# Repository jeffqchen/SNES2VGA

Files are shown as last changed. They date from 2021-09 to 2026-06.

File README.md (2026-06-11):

# SNES2VGA

SNES2VGA Dongle for Nintendo Consoles

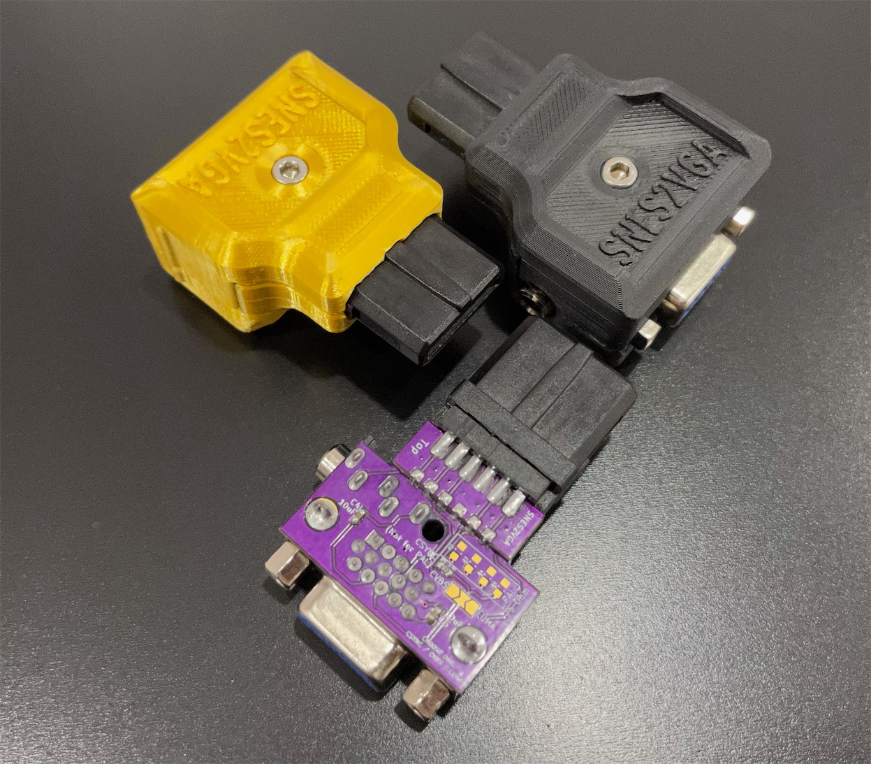
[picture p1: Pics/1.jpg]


## Introduction

This dongle takes the AV Multi output used on various Nintendo consoles and adapts them into HD15 (VGA), so you can use the commonly available VGA cable for transmitting RGBs video and stereo audio.

Note that consoles usually require RGB mods in order to output RGBs signal.

### Console Compatibility

#### Nintendo Entertainment System / Nintendo Famicom

The NES/Famicom do not generate or output RGB signals natively. They generate composite video and output it as-is or encode it to RF.

For them to output RGB, modding it with an [NESRGB](https://etim.net.au/nesrgb/) and the [Nintendo AV Multi style port](https://www.laserbear.net/products/nes-front-loader-snap-fit-multiout) is required.

*(If you installed an 8 or 9-pin MiniDin port, please check my [8DIN2VGA](https://github.com/jeffqchen/8DIN2VGA) and [9DIN2VGA](https://github.com/jeffqchen/9DIN2VGA) projects instead.)*

---------

#### Super NES / Super Famicom (Jr.)

- NTSC consoles not output RGB signals natively, and need to be modded to restore RGB output with [SNES RGB Bypass](https://github.com/borti4938/SNES_RGB_Bypass).
- PAL consoles output an RGB signal, but outputs 12V on the same pin where CSync is output on a NTSC console. Care must be taken when assembling the dongle.

---------

#### Nintendo 64

No native RGB output. Different models require different levels of modding to restore RGB output ([Simple RGB Bypass](https://voultar.com/index.php?route=product/product&product_id=50), [N64RGB](https://etim.net.au/n64rgb/), etc)

---------

#### GameCube

- NTSC consoles don't output RGB signals. RGB modding, such as [GCVideo](https://github.com/ikorb/gcvideo), is required.
- PAL consoles support RGB output natively, however the same `12V on CSync ordeal` is still present.

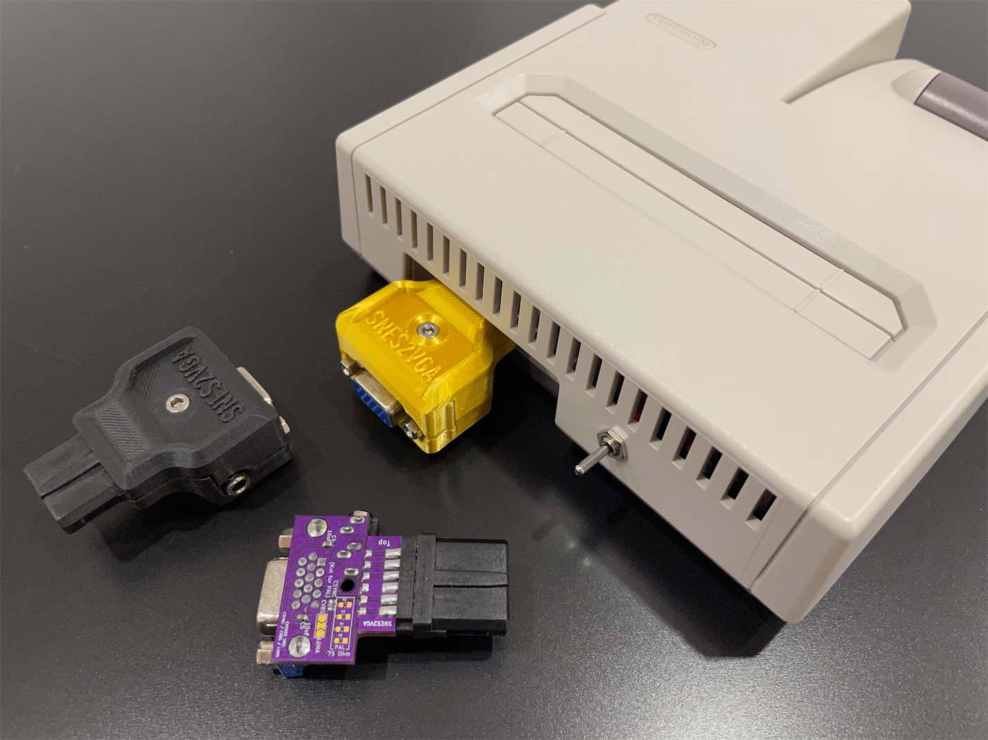
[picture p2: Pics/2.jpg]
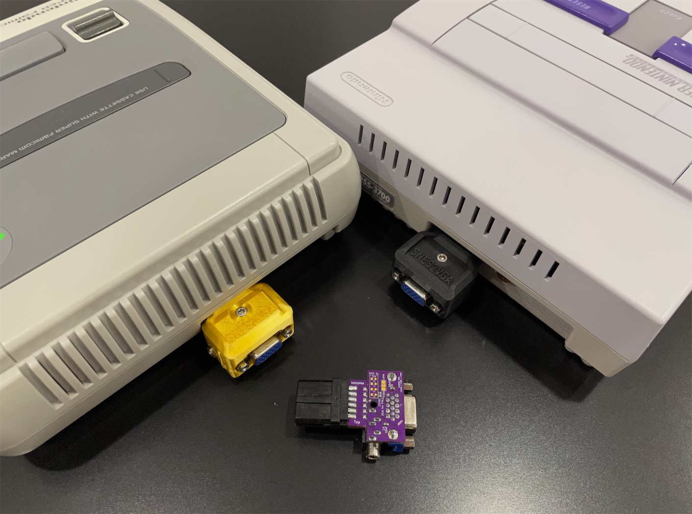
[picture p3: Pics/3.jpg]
 

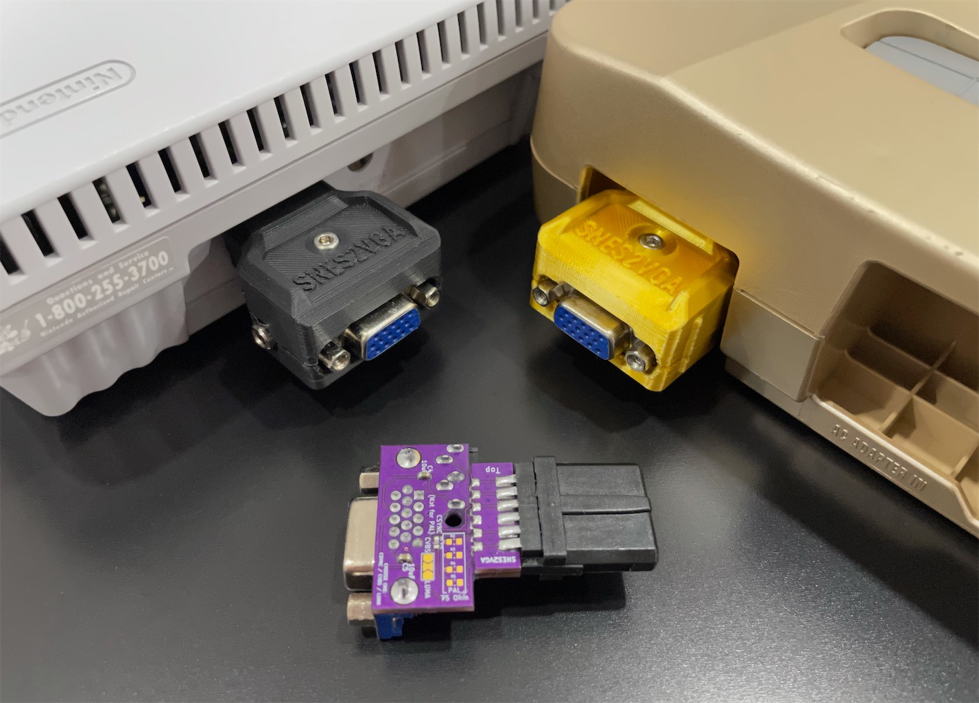
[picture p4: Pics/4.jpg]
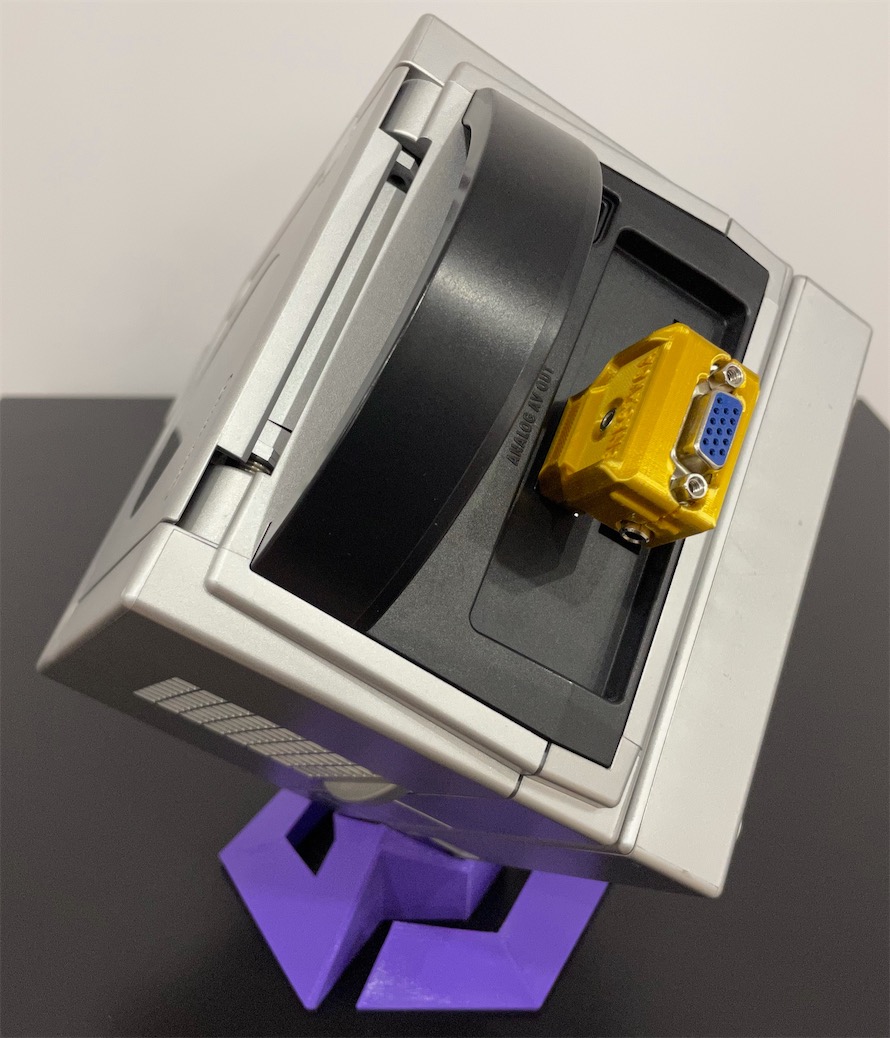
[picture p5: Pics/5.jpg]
 

## Sync

You can choose among CSync, Luma and composite video as your sync signal with the jumper on the PCB.

**WARNING**: PAL consoles output 12V on the CSync pin. CSync related components should NOT be populated if you are building this dongle for a PAL console.

## Audio

Audio can be sent within the VGA cable, or broken out from the 3.5mm jack on the dongle. Buzzing may be noticeable when audio is transmitted through the VGA cable in certain scenes in certain games. This is due to insufficient shielding in most VGA cables. If you find the buzzing to be annoying, please use the 3.5mm jack on the dongle for audio outputting. This will ensure the cleanest audio output.

------

## Variation - [N64D2VGA](./N64D2VGA)

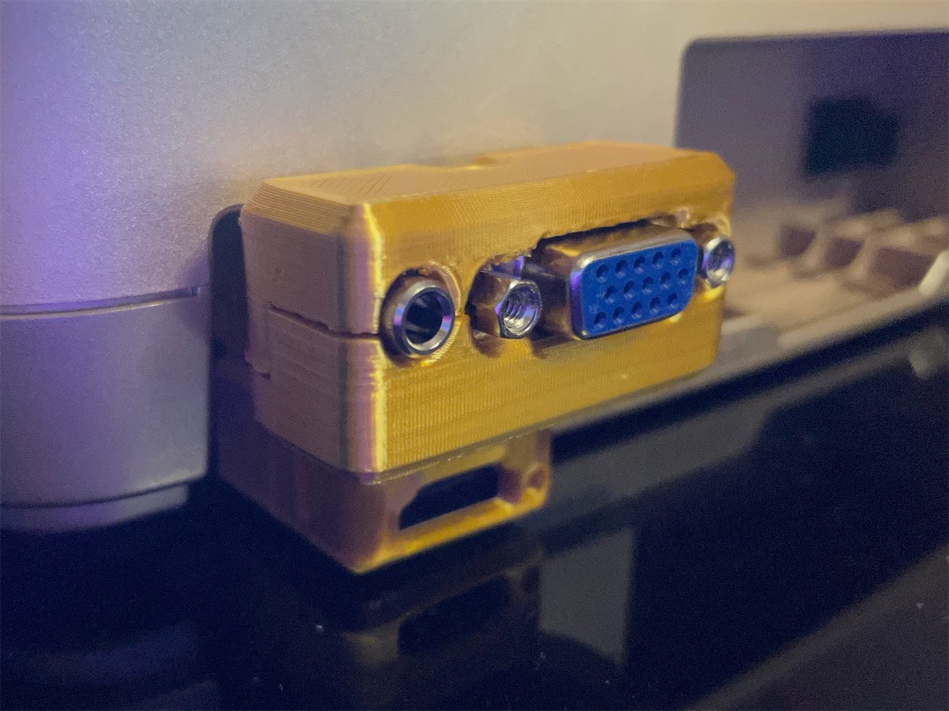
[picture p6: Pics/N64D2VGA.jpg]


This one works with my [N64Digital mini HDMI to Full HDMI Dongle](../../../N64Digital-Mini-To-Full-HDMI-Adapter) so you could achieve analogue RGBS & digital dual output with full sized plugs without interference.

-----

## Parts

### Common Parts

- PCB
  - [Main](https://oshpark.com/projects/JstxPxyZ)
  - [Sub](https://oshpark.com/shared_projects/RpSdS3qo)

- Nintendo AV Plug - [Link](https://github.com/jeffqchen/JeffParts/blob/main/Connectors/Nintendo%20AV%20Plug/info.md)

- VGA Port Slim, Female - [Link](https://github.com/jeffqchen/JeffParts/blob/main/Connectors/HD15/Slim/Female%20PCB/info.md)

- Vertical 3.5mm Headphone Jack - [Link](https://github.com/jeffqchen/JeffParts/blob/main/Connectors/3.5mm%20Audio%20Jack/Vertical%205-Pin%20PCB/info.md)

- [1x] M3x20mm screw and nut - [Link](https://github.com/jeffqchen/JeffParts/blob/main/Parts/M2%20M3%20Hex%20Screw%20%26%20Nut/info.md)

- [2x] Imperials 0603 SMD Capacitor 6.3V 10uF - C4, C5

- 3D Printed Shell
  - [Top](https://github.com/jeffqchen/SNES2VGA/blob/main/3D%20Print/SNES2VGA/Top.stl)
  - [Bottom](https://github.com/jeffqchen/SNES2VGA/blob/main/3D%20Print/SNES2VGA/Bottom.stl)

---

### NTSC Configuration

- C1, C2, C3: [3x] 220uF / 6.3V / Imperial 1206 Size - [Link](https://github.com/jeffqchen/JeffParts/blob/main/Components/220uF%20SMD%20Cap/info.md)
- [1x] Imperial SMD 0603 Resistor 470 Ohm - R1, **ONLY** if you choose CSync

---

### PAL Configuration

- C6: [1x] 220uF / 6.3V / Imperial 1206 Size - [Link](https://github.com/jeffqchen/JeffParts/blob/main/Components/220uF%20SMD%20Cap/info.md)
- [4x] Imperial SMD 0603 Resistor 75 Ohm - R2, R3, R4, R5

---

## Printing the Shell

Print the files with the split face facing downwards.

Print with support.

For a better mating surface finishing, use raft for bed adhesion.

---

## PCB Assembly

### Solder sub PCB to the main

First, align the sub PCB on top of the main PCB, align with the helper line and make sure the correct sides are facing the outside. Solder the two outside-most castellated pins and pads one by one, making sure the outside of the two boards are flush, so the plug can be soldered properly. Then proceed to solder the rest of the castellated pins to the pads.

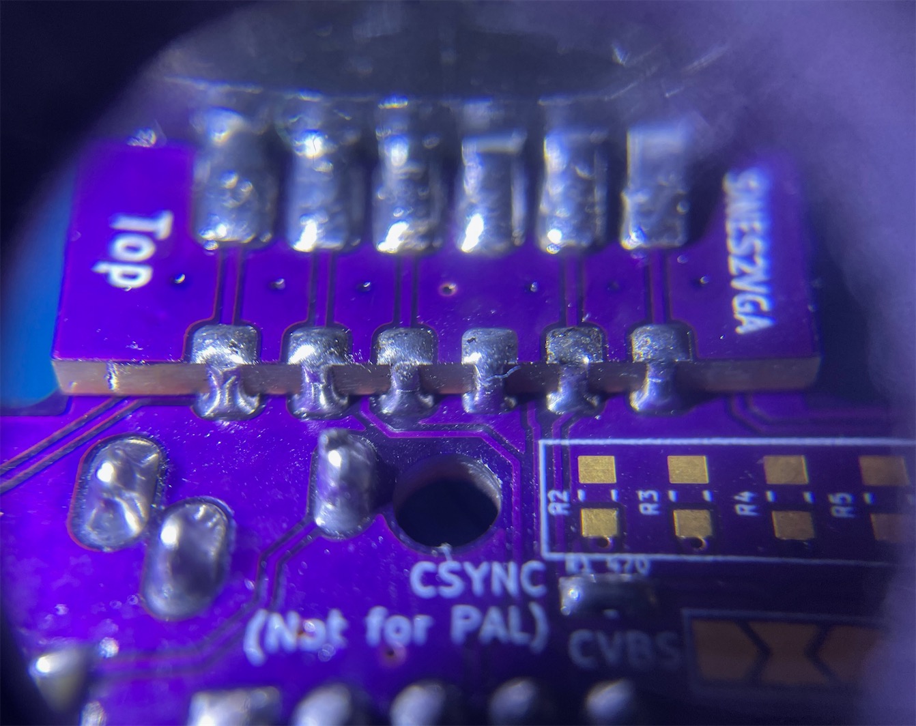
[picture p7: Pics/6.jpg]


### Solder on the video plug

Next, take a Nintendo video plug. Note the pins on the soldering side are sticking out straight. Now **bend** both rows of the pins inwards, with the help of the edge of a table. This way, the pins will actually be able to touch the pads on the PCB compound.

Tuck the plug onto the compound PCB. Make sure the plug is pointing the correct way up - the notched side of the plug is up, and the side with the smaller sub PCB is up. Align the pins to the pads as good as possible. Make sure there is no gap between the plug and the PCB on the mating edge. Then, solder one pin on each side with a generous amount of solder. Remelt and adjust the position if needed. Then proceed and solder the rest of the pins to the PCB with generous amount of solder.

### SMD Components

Solder on the SMD components. Note for NTSC and PAL consoles, the component configurations are **quite different**. Please follow the instructions on the silk screen.

---

### NTSC Configuration

- Populate C1, C2, C3

#### Choose A Sync

##### CSync
- Populate R1
- Leave JP2 open

##### Composite (CVBS) or Luma As Sync
- Do NOT populate R1
- Short one side of jumper JP1 for CVBS or Luma. Choose only **ONE**
- Short JP2

---

### PAL Configuration

- **DO NOT** populate R1
- Populate R2, R3, R4, R5
- Short C1, C2, C3 with individual conductors
- Populate C6

#### Choose A Sync between Composite (CVBS) or Luma

- Short one side of jumper JP1 for CVBS (recommended) or Luma. Choose only **ONE**
- Leave JP2 open

---

### Through hole components

Solder on the through hole VGA and 3.5mm audio port. Note they are supposed to be on the bottom side of the PCB. Pay attention to the silk screen markings.

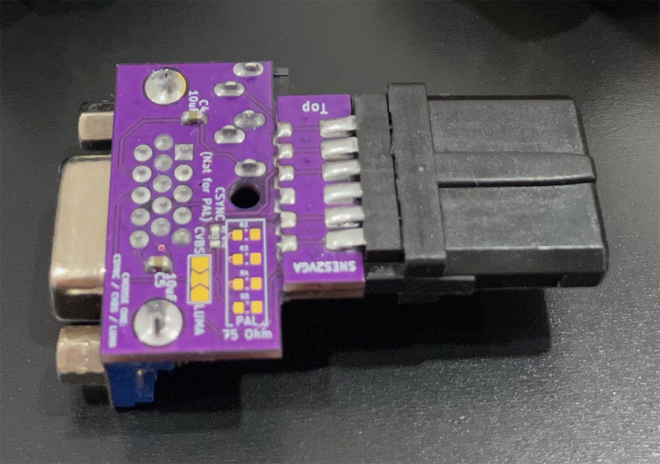
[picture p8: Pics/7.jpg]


---

## Final Assembly

Tuck the assembled PCB into one side of the shell. Make sure the video plug fits correctly in. Then drop the other side of the shell in and slowly bring the two sides to a close. Inspect the shells for any remaining support material if you can't correctly close it up. Finally, put in the screw and nut to secure the whole assembly.

---
## Misc Info
Non-CSync signals are incompatible with the AV3 input on the OSSC. Only TTL CSync works with AV3 on the OSSC.

---

## Special Thanks

Mike Chi - Beloved creator of RetroTink
- https://www.retrotink.com

Javier Rodas
- https://twitter.com/JaviRodasG

---

Shield: [][cc-by-sa]

This work is licensed under a
[Creative Commons Attribution-ShareAlike 4.0 International License][cc-by-sa].

[][cc-by-sa]

[cc-by-sa]: http://creativecommons.org/licenses/by-sa/4.0/
[cc-by-sa-image]: https://licensebuttons.net/l/by-sa/4.0/88x31.png
[cc-by-sa-shield]: https://img.shields.io/badge/License-CC%20BY--SA%204.0-lightgrey.svg

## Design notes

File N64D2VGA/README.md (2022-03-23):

# N64D2VGA

N64D2VGA Dongle for Nintendo 64 Console.

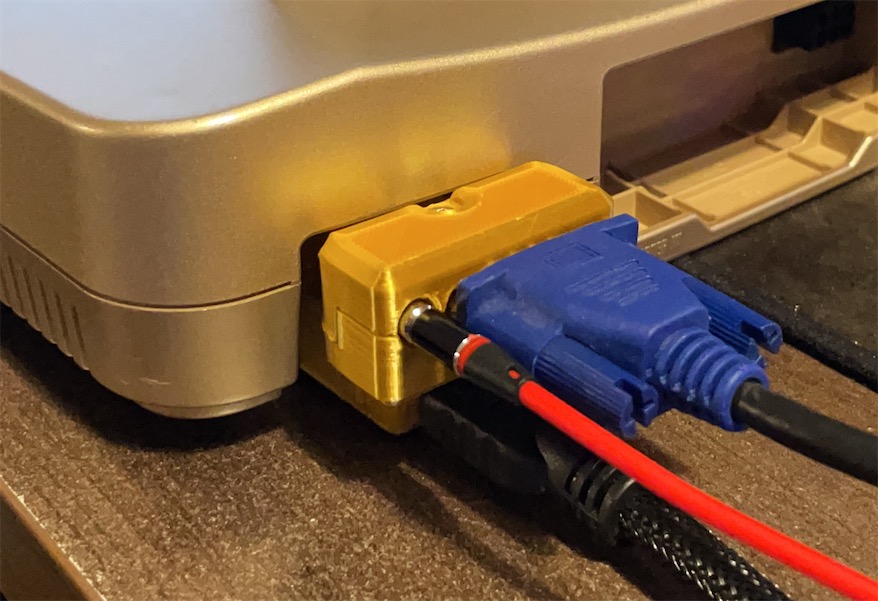
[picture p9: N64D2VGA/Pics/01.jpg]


## Introduction

This dongle takes the RGBS signal from the AV Multi output on a Nintendo 64 console and adapts it into HD15 (VGA), so you can use the commonly available VGA cable for transmitting RGBs video and stereo audio.

This is designed to work with the [N64Digital mini HDMI to Full HDMI Dongle](https://github.com/jeffqchen/N64Digital-Mini-To-Full-HDMI-Adapter). You could achieve analogue & digital dual output with full sized plugs without interference.

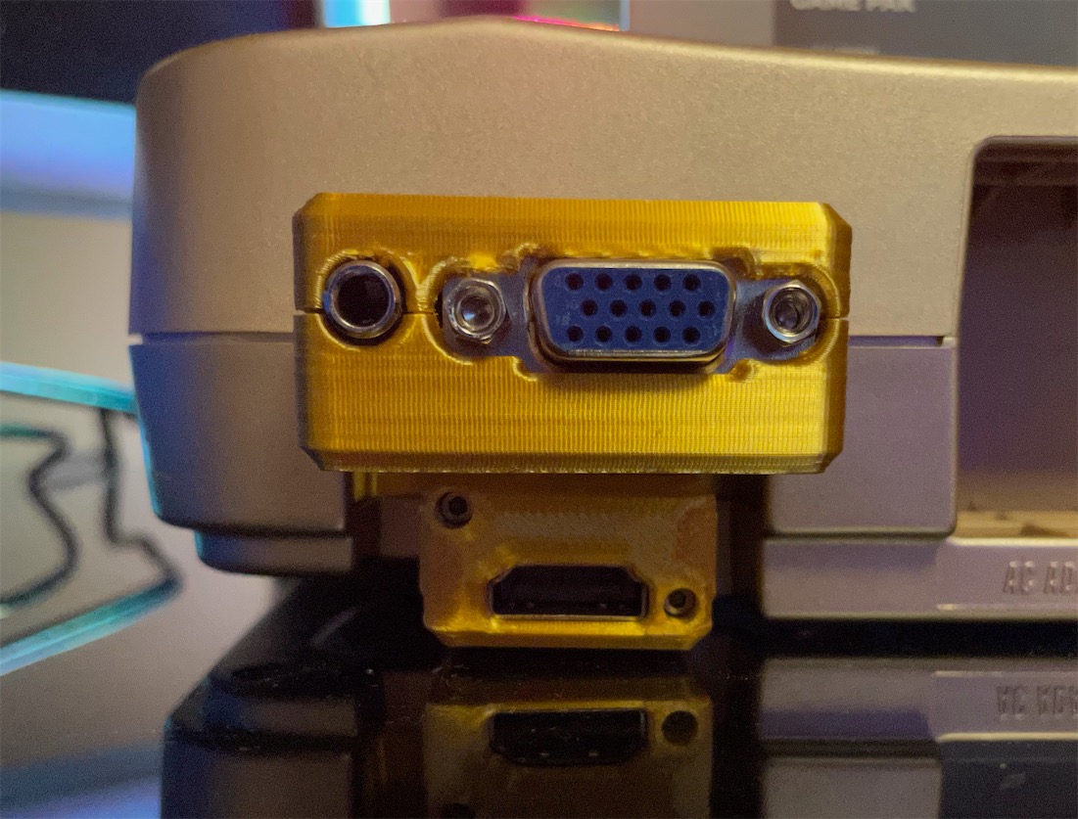
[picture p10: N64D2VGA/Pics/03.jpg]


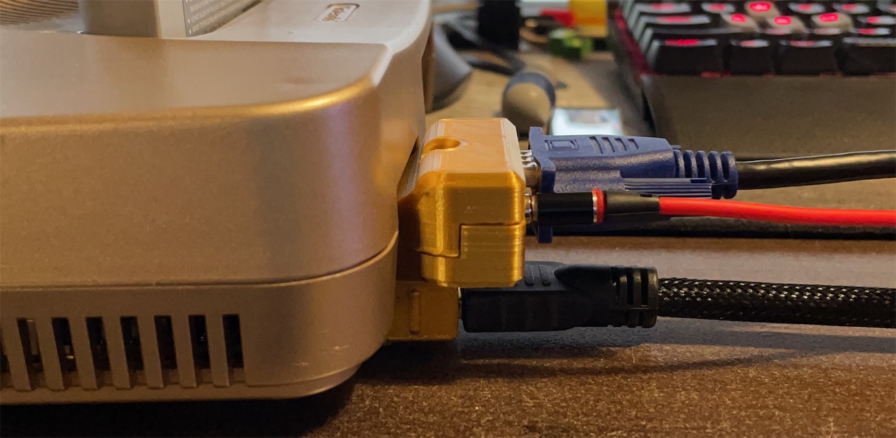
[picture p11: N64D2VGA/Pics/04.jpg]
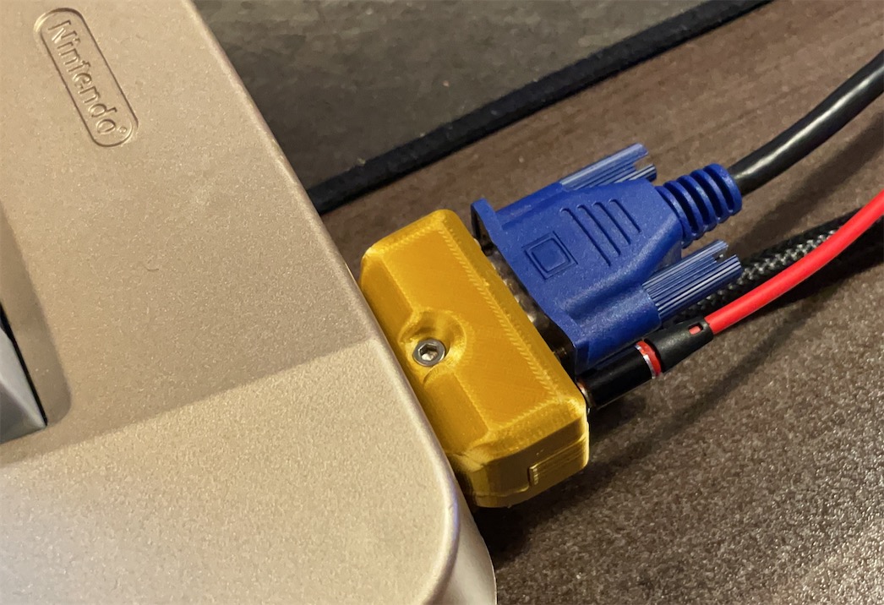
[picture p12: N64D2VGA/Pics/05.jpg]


Note that the Nintendo 64 requires a mod in order to output RGBS signal, such as:

- [N64Digital](https://docs.pixelfx.co/N64Digital-Details.html)
- Simple RGB mod ([Voultar's](https://voultar.com/index.php?route=product/product&product_id=50&tracking=5824d766cf098), [Borti's](https://github.com/borti4938/n64rgb/tree/master/simpleRGBamp))
- [N64RGB](https://github.com/borti4938/n64rgb)

## Sync

You can choose among CSync, Luma and composite video as your sync signal with the jumper on the PCB.

Note PAL console does not support CSync and you should not populate CSync related components.

## Audio

Audio can be sent within the VGA cable, or broken out from the 3.5mm jack on the dongle. Buzzing may be noticeable when audio is transmitted through the VGA cable in certain scenes in certain games. This is due to insufficient shielding in most VGA cables. If you find the buzzing to be annoying, please use the 3.5mm jack on the dongle for audio outputting. This will ensure the cleanest audio output.

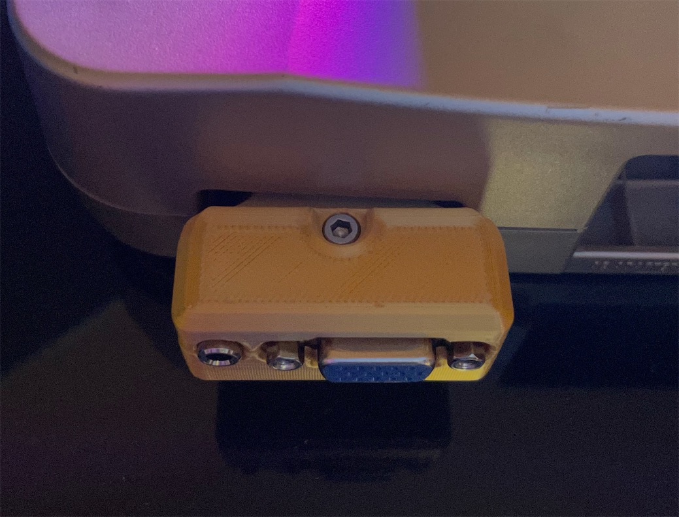
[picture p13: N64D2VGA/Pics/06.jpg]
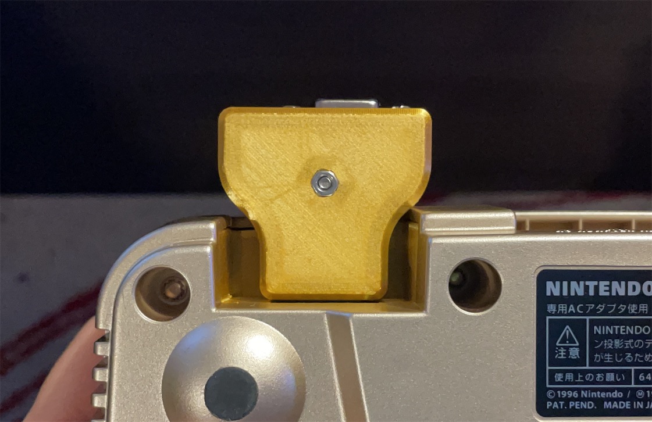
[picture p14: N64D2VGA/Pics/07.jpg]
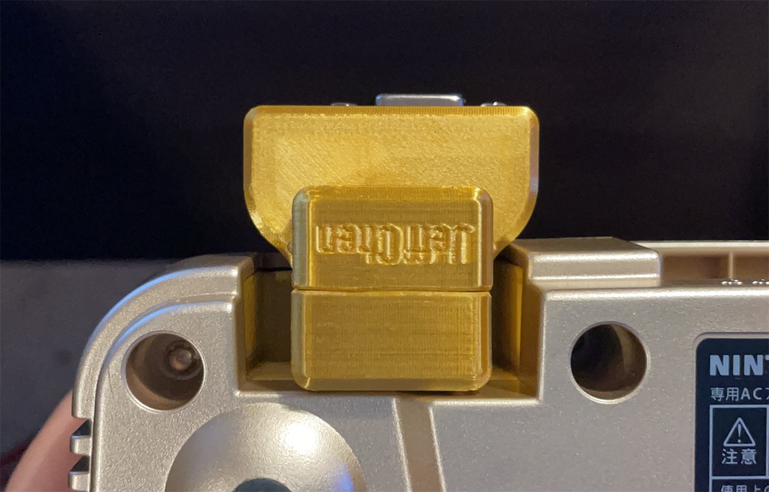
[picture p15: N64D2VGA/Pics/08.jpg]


-----

## Parts

### Common Parts

- PCB
  - [Main](https://oshpark.com/shared_projects/gnmrDMrM)
  - [Sub](https://oshpark.com/shared_projects/ERxGMR9J)

- Nintendo AV Plug - [Link](https://github.com/jeffqchen/JeffParts/blob/main/Connectors/Nintendo%20AV%20Plug/info.md)

- VGA Port Slim, Female - [Link](https://github.com/jeffqchen/JeffParts/blob/main/Connectors/HD15/Slim/Female%20PCB/info.md)

- Vertical 3.5mm Headphone Jack - [Link](https://github.com/jeffqchen/JeffParts/blob/main/Connectors/3.5mm%20Audio%20Jack/Vertical%205-Pin%20PCB/info.md)

- M3x20mm screw and nut - [Link](https://github.com/jeffqchen/JeffParts/blob/main/Parts/M2%20M3%20Hex%20Screw%20%26%20Nut/info.md)

- [2x] 0603 Capacitor 6.3V 10uF - C4, C5

- 3D Printed Shell - Top & Bottom

---

### NTSC Configuration

- [1x] 0603 Resistor 470 Ohm - R1, **ONLY** if you choose CSync
- [3x] SMD electrolytic Capacitor 220uF - C1, C2, C3

---

### PAL Configuration

- [4x] 0603 Resistor 75 Ohm - R2, R3, R4, R5

---

## Assembly

Please refer to the [SNES2VGA assembly guide](https://github.com/jeffqchen/SNES2VGA#printing-the-shell), as they are very similar.

---

## Special Thanks

Mike Chi - Beloved creator of RetroTink
- https://www.retrotink.com

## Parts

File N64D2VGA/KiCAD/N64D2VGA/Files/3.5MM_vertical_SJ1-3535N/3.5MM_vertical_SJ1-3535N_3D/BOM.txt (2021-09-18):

3DX_CUI_DEVICES_Supplier: CUI Devices
3DX_CUI_DEVICES_Description: 3.5 mm Right-Angle Stereo Jack, 5 Pin PCB Mount, Non-Threaded
3DX_CUI_DEVICES_Model Number: SJ1-3535N

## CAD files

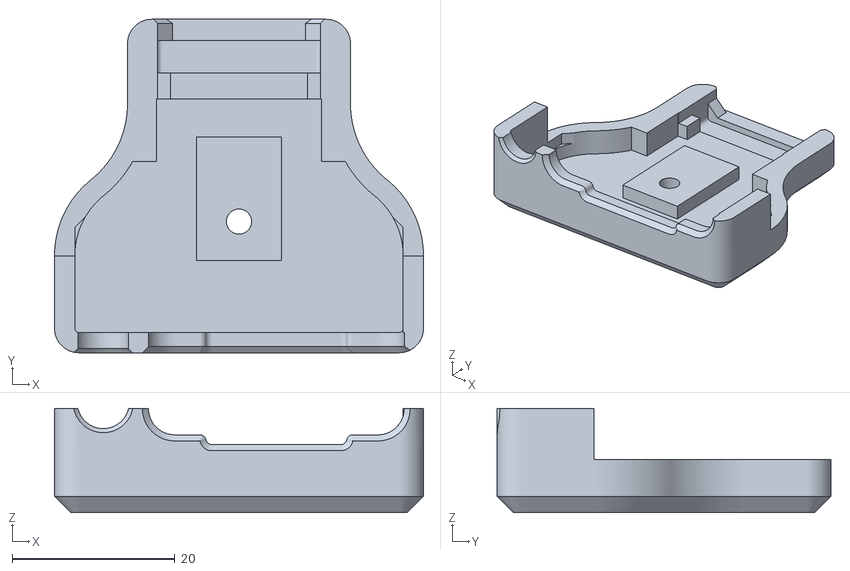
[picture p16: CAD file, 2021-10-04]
N64D2VGA/3D Print/Bottom.stl
45.4 x 41.0 x 12.8

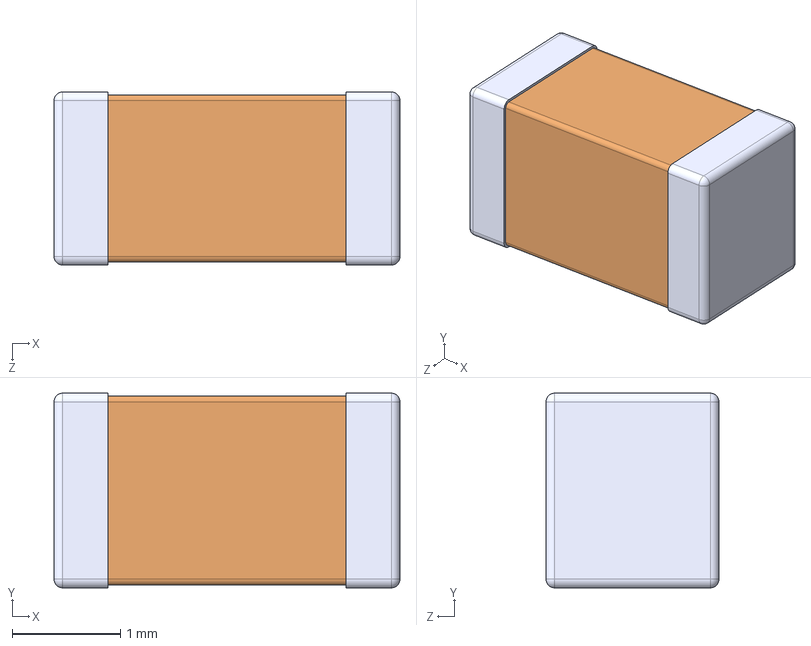
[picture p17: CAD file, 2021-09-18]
N64D2VGA/KiCAD/N64D2VGA/Files/1206 Cap Samsung/CL31A107MQHNNNE.step
3.20 x 1.80 x 1.60 mm

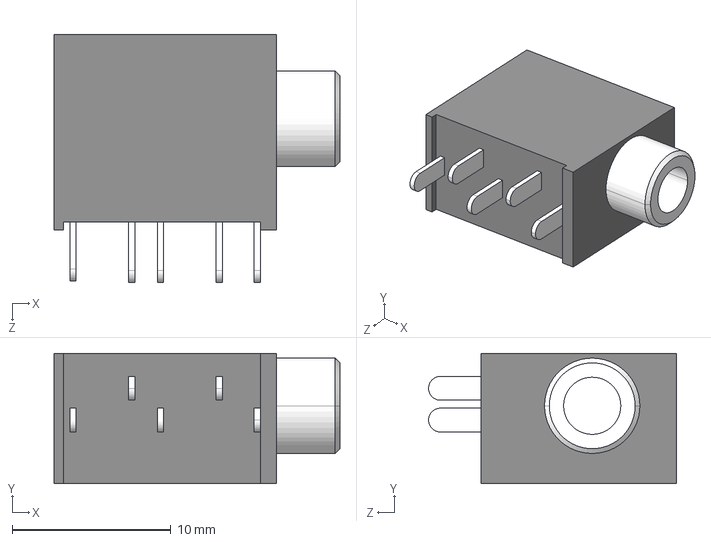
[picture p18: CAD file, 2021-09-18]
N64D2VGA/KiCAD/N64D2VGA/Files/3.5MM_vertical_SJ1-3535N/3.5MM_vertical_SJ1-3535N_3D/CUI_DEVICES_SJ1-3535N.step
18.0 x 8.20 x 15.6 mm

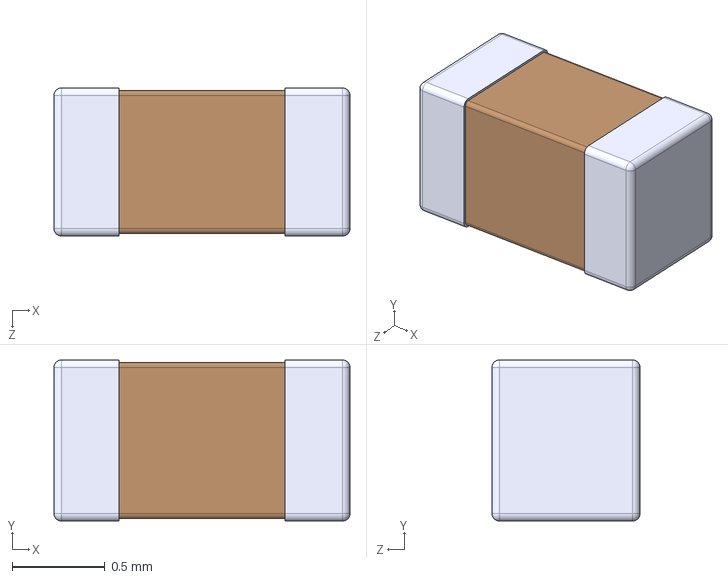
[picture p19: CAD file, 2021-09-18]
N64D2VGA/KiCAD/N64D2VGA/Files/C0603C180K4HAC7867/C0603C180K4HAC7867.step
1.60 x 0.87 x 0.8 mm

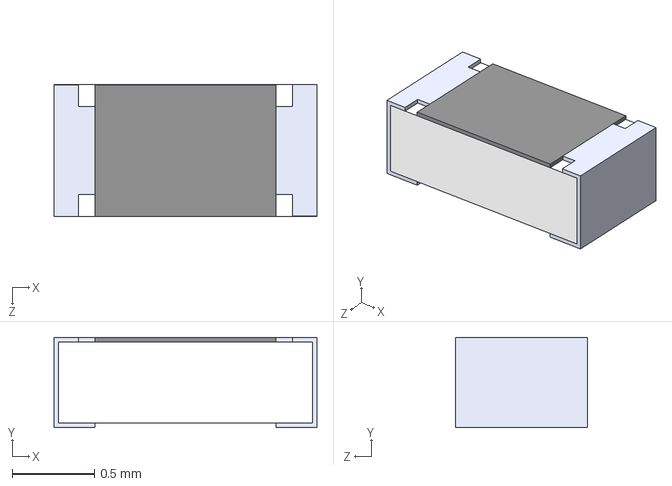
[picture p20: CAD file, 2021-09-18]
N64D2VGA/KiCAD/N64D2VGA/Files/RE0603FRE071KL/RE0603FRE071KL.step
1.60 x 0.55 x 0.8 mm

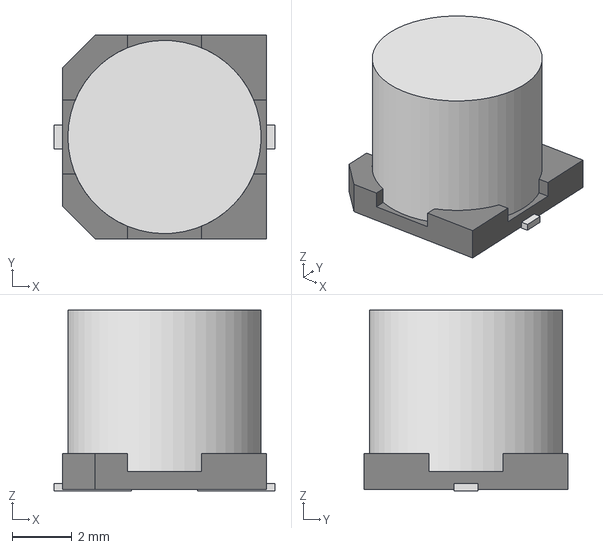
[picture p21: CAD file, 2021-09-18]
N64D2VGA/KiCAD/N64D2VGA/Files/ul_PCS0J221MCL1GS/2021-07-23_05-10-58/STEP/PCAP_6_3x6-ELECT_NCA.step
7.39 x 6.81 x 6.05 mm

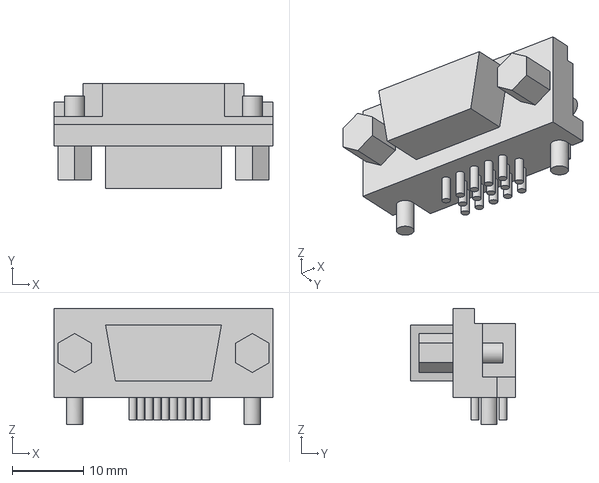
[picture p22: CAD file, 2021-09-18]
N64D2VGA/KiCAD/N64D2VGA/Files/VGA Female Slim.step
30.8 x 14.8 x 16.4 mm

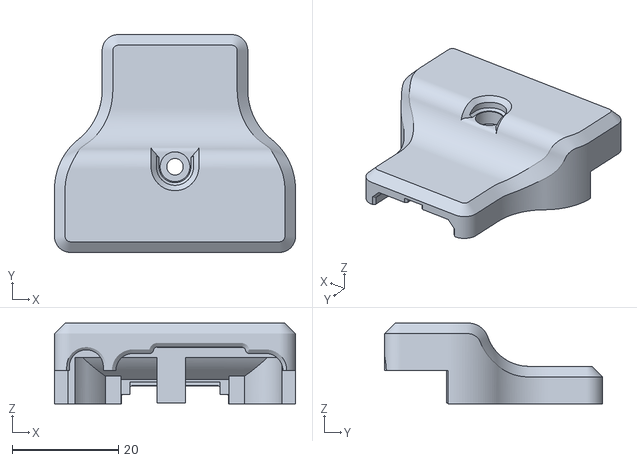
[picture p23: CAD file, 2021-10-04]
N64D2VGA/3D Print/Top.stl
45.4 x 41.0 x 15.3

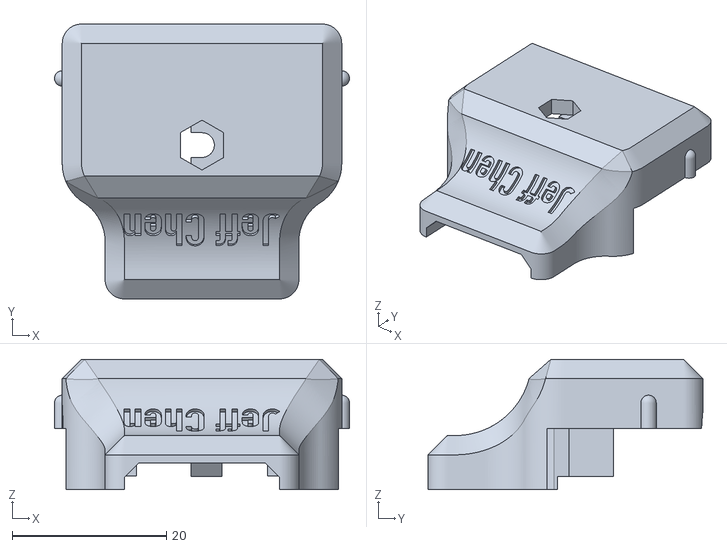
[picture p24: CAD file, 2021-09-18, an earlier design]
3D Print/SNES2VGA/Bottom.stl
38.2 x 35.6 x 16.8

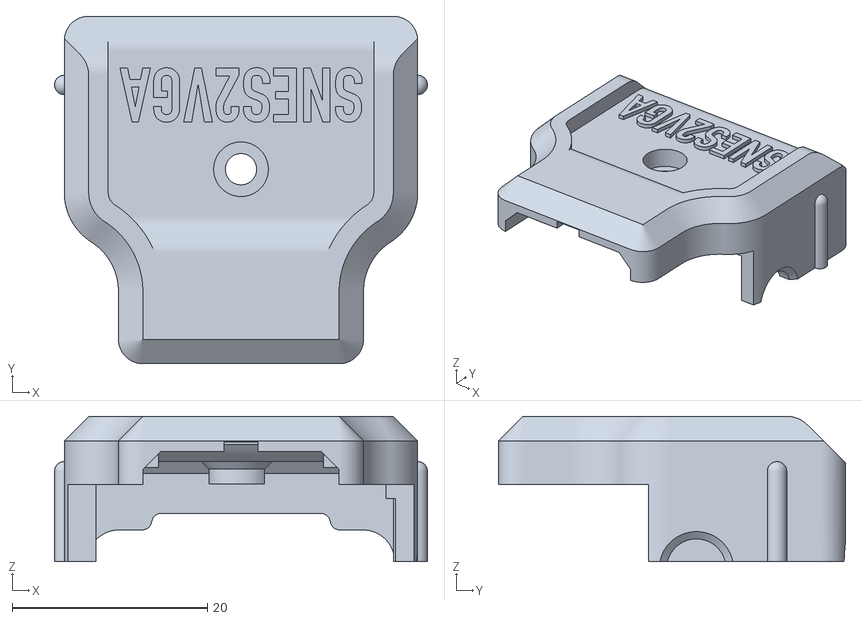
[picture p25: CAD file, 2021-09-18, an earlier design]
3D Print/SNES2VGA/Top.stl
38.2 x 35.6 x 14.9

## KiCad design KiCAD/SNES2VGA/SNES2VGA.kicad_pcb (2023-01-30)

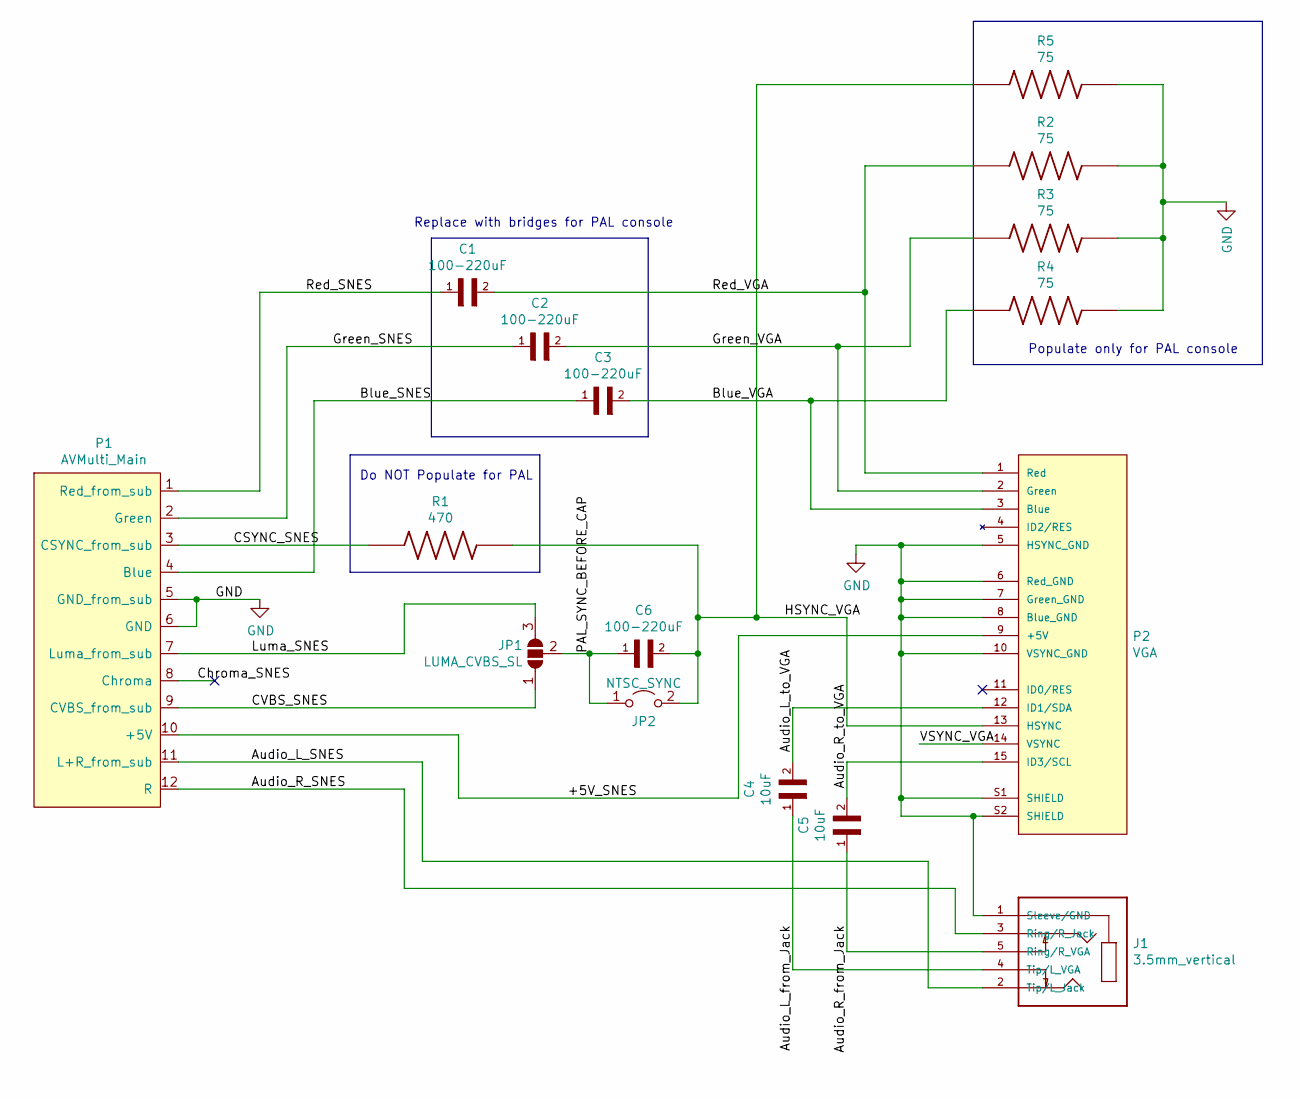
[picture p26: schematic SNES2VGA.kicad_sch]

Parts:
C1, C2, C3, C6: 100-220uF; Cap_SMD_1206
C4, C5: 10uF; Cap_SMD_0603
J1: 3.5mm_vertical; PARTREV 1.01
JP1: LUMA_CVBS_SL; SolderJumper-3_P1.3mm_Open_RoundedPad1.0x1.5mm
JP2: NTSC_SYNC; SolderJumper-2_P1.3mm_Open_RoundedPad1.0x1.5mm
P1: AVMulti_Main; AV_Multi_Main
P2: VGA; VGA_female_rightangle_slim; PARTREV N/A
R1: 470; Resistor_SMD_0603
R2, R3, R4, R5: 75; Resistor_SMD_0603

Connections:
/+5V_SNES: P1.10 (+5V), P2.9 (+5V)
/Audio_L_SNES: J1.2 (Tip/L_Jack), P1.11 (L+R_from_sub)
/Audio_L_from_Jack: C4.1, J1.4 (Tip/L_VGA)
/Audio_L_to_VGA: C4.2, P2.12 (ID1/SDA)
/Audio_R_SNES: J1.3 (Ring/R_Jack), P1.12 (R)
/Audio_R_from_Jack: C5.1, J1.5 (Ring/R_VGA)
/Audio_R_to_VGA: C5.2, P2.15 (ID3/SCL)
/Blue_SNES: C3.1, P1.4 (Blue)
/Blue_VGA: C3.2, P2.3 (Blue), R4.1
/CSYNC_SNES: P1.3 (CSYNC_from_sub), R1.1
/CVBS_SNES: JP1.1 (A), P1.9 (CVBS_from_sub)
/Chroma_SNES: P1.8 (Chroma)
/Green_SNES: C2.1, P1.2 (Green)
/Green_VGA: C2.2, P2.2 (Green), R3.1
/HSYNC_VGA: C6.2, JP2.2 (B), P2.13 (HSYNC), R1.2, R5.1
/Luma_SNES: JP1.3 (B), P1.7 (Luma_from_sub)
/PAL_SYNC_BEFORE_CAP: C6.1, JP1.2 (C), JP2.1 (A)
/Red_SNES: C1.1, P1.1 (Red_from_sub)
/Red_VGA: C1.2, P2.1 (Red), R2.1
/VSYNC_VGA: P2.14 (VSYNC)
GND: J1.1 (Sleeve/GND), P1.5 (GND_from_sub), P1.6 (GND), P2.5 (HSYNC_GND), P2.6 (Red_GND), P2.7 (Green_GND), P2.8 (Blue_GND), P2.10 (VSYNC_GND), P2.S1 (SHIELD), P2.S2 (SHIELD), R2.2, R3.2, R4.2, R5.2

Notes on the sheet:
Do NOT Populate for PAL
Replace with bridges for PAL console
Populate only for PAL console

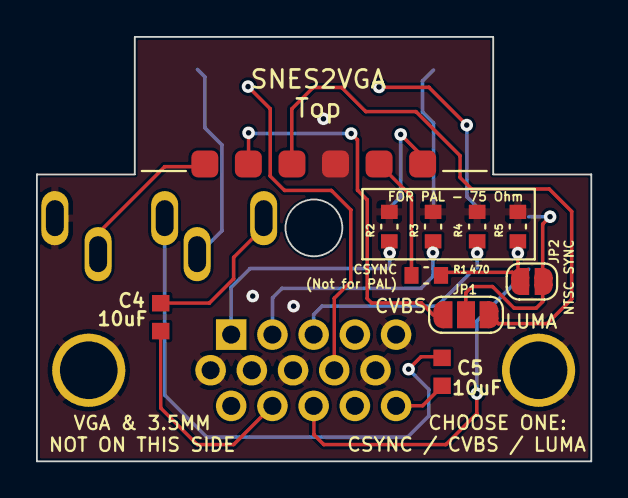
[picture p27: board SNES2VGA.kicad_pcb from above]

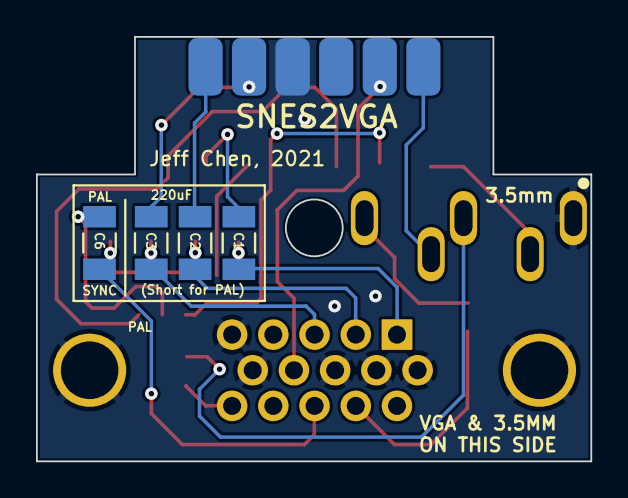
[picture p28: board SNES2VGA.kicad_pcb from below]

Board: 2 copper layers, 30.8 x 23.6 mm, 16 parts (6 on the bottom side), 19 nets.

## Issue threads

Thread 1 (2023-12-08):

Make screw hole slightly larger?

amaiorano, 2023-12-08:
Hello,

I printed `top.stl` and found that my M3x20mm screw head was slightly too large to fit in the hole:

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

I ended up modifying the STL in Fusion and made it slightly larger, with a diameter of 5.8mm:

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

I bought [my screw kit on amazon.ca](https://www.amazon.ca/gp/product/B09TSKT4CZ/ref=ppx_yo_dt_b_search_asin_image?ie=UTF8&psc=1), so I suspect I'm not the only one who may run into this issue. Would it possible for you to make the holes slightly larger in the official design?

P.S. Thank you for this awesome project!

jeffqchen, 2023-12-08:
I expected people to follow the link and purchase the proper (and nice-looking) screws I used in the design. You are welcome to make the hole bigger for yourself.

jeffqchen, 2023-12-08:
My bad. I don't think I've used the last type in any of my designs. Maybe I included it there just to offer more information. I'll remove it later.

amaiorano, 2023-12-08:
Fair enough, it's your design. Thanks again.

Closed 2023-12-08.

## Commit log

2021-09-18 Initial upload
    [Bottom.3mf, Bottom.stl, C0603C180K4HAC7867.step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]
2021-10-04 Add N64D2VGA Files
    [C0603C180K4HAC7867.step, CL31A107MQHNNNE.step, CUI_DEVICES_SJ1-3535N.step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]
2021-10-04 Rearrange 3D print files
    [Bottom.3mf, Bottom.stl, Top.3mf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]
2021-10-24 Update PCB
    [SNES2VGA-B_Mask.gbr, SNES2VGA-B_Paste.gbr, SNES2VGA-B_SilkS.gbr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]
2021-12-31 Update N64D2VGA Page
    [C0603C180K4HAC7867.step, CL31A107MQHNNNE.step, CUI_DEVICES_SJ1-3535N.step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]
2021-12-31 Add 3D Print Files
    [Bottom.stl, Top.stl]
2022-03-23 Update 3.5mm URL
2023-01-30 KiCAD Project Revision
    [SNES2VGA-B_Mask.gbr, SNES2VGA-B_Paste.gbr, SNES2VGA-B_SilkS.gbr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]

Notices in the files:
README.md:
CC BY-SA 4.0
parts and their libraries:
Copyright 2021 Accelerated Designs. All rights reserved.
